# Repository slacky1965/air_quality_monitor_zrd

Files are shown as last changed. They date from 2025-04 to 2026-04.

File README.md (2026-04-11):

# <a id="Top">Air Quality Monitor Zigbee</a>

---

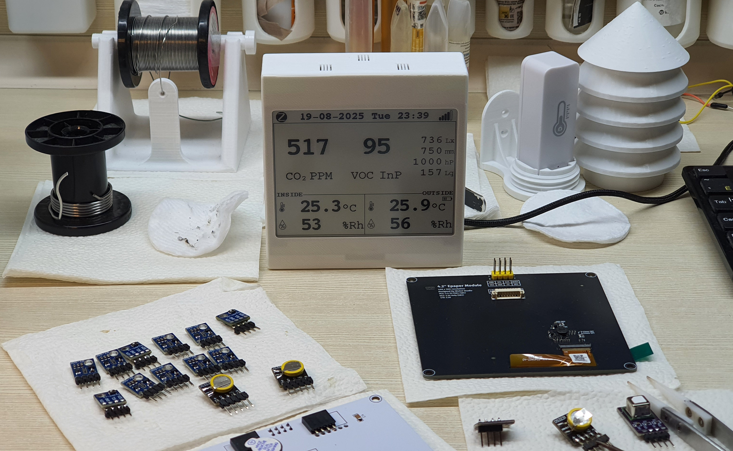
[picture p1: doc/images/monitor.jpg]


---

[Статья на Habr'е](https://habr.com/ru/articles/938388)

[Repository air_quality_monitor_zrd](https://github.com/slacky1965/air_quality_monitor_zrd)

---

* [Описание](#description)
* [Железо](#hardware)
* [Софт](#software)  
* [Принцип работы](#firmware)
* [Настройка](#settings)

## <a id="description">Описание</a>

- Устройство представлят из себя домашний бытовой монитор (далее просто `Монитор`) со встроенными датчиками качества воздуха и климата, показания которых выводятся на экран `epaper` 4.2" и передаются в сеть `Zigbee`.
- `Монитор` выводит следующие показания внутренних датчиков:
	- углекислого газа `CO2`,
	- летучих органичесикх веществ `VOC`,
	- температуры,
	- влажности,
	- атмосферного давления,
	- освещенности.
- `Монитор` имеет возможность отображать показания температуры, влажности и заряда батареи с внешнего датчика напрямую, минуя координатор (прямой биндинг).
- `Монитор` имеет возможность управлять внешним устройством (реле/вентилятор) напрямую, минуя координатор (прямой биндинг) на основании показаний датчиков CO2 и VOC, посылая команды On-Off.
 - `Монитор` может отображать данные в горизонтальном или вертикальном положении, а также менять режим вывода - черное на белом или белое на черном.
- Настраиваемые параметры сохраняет в энергонезависимой памяти модуля `ZTU`.
- Взаимодейстивие с "умными домами" через `zigbee2mqtt`.
- Первоначальная настройка происходит через web-интерфейс `zigbee2mqtt`.
- Подключиться к сети или покинуть сеть `Zigbee` - удерживать кнопку более 5 секунд (светодиод должен погаснуть и начать моргать красным цветом). Время присоединения к сети - полторы минуты (или пока моргает светодиод).
- При одиночном нажатии кнопки `Монитор` высылает отчет по всем показаниям.
- `Монитор` питается от источника постоянного тока напряжением 5 вольт через разъем `USB Type-C` и является роутером.

---

## <a id="hardware">Железо</a>

- В `Мониторе` установлены следующие датчики и модули:
	- `SCD40`      - высокоточный цифровой датчик углекислого газа (`CO2`).
	- `SGP40`      - цифровой датчик летучих органических соединений (`VOC`) от `Sensirion`.
	- `BME280`     - комбинированный цифровой датчик влажности, давления и температуры фирмы `Bosch Sensortec`.
	- `BH1750`     - цифровой датчик освещённости.
	- `DS3231`     - часы реального времени (допускается установка `DS1307`).
	- `WS2812B` 	   - адресные светодиоды, которые помогают визуально по цвету определить качество воздуха.
	- `ZTU`        - модуль `Zigbee` от фирмы `Tuya`, выполенный на чипе `TLSR8258F1KET32` фирмы `Telink`.
	- `WeAct 4.2"` - epaper экран от `WeAct Studio`.

### Схема `Монитора`

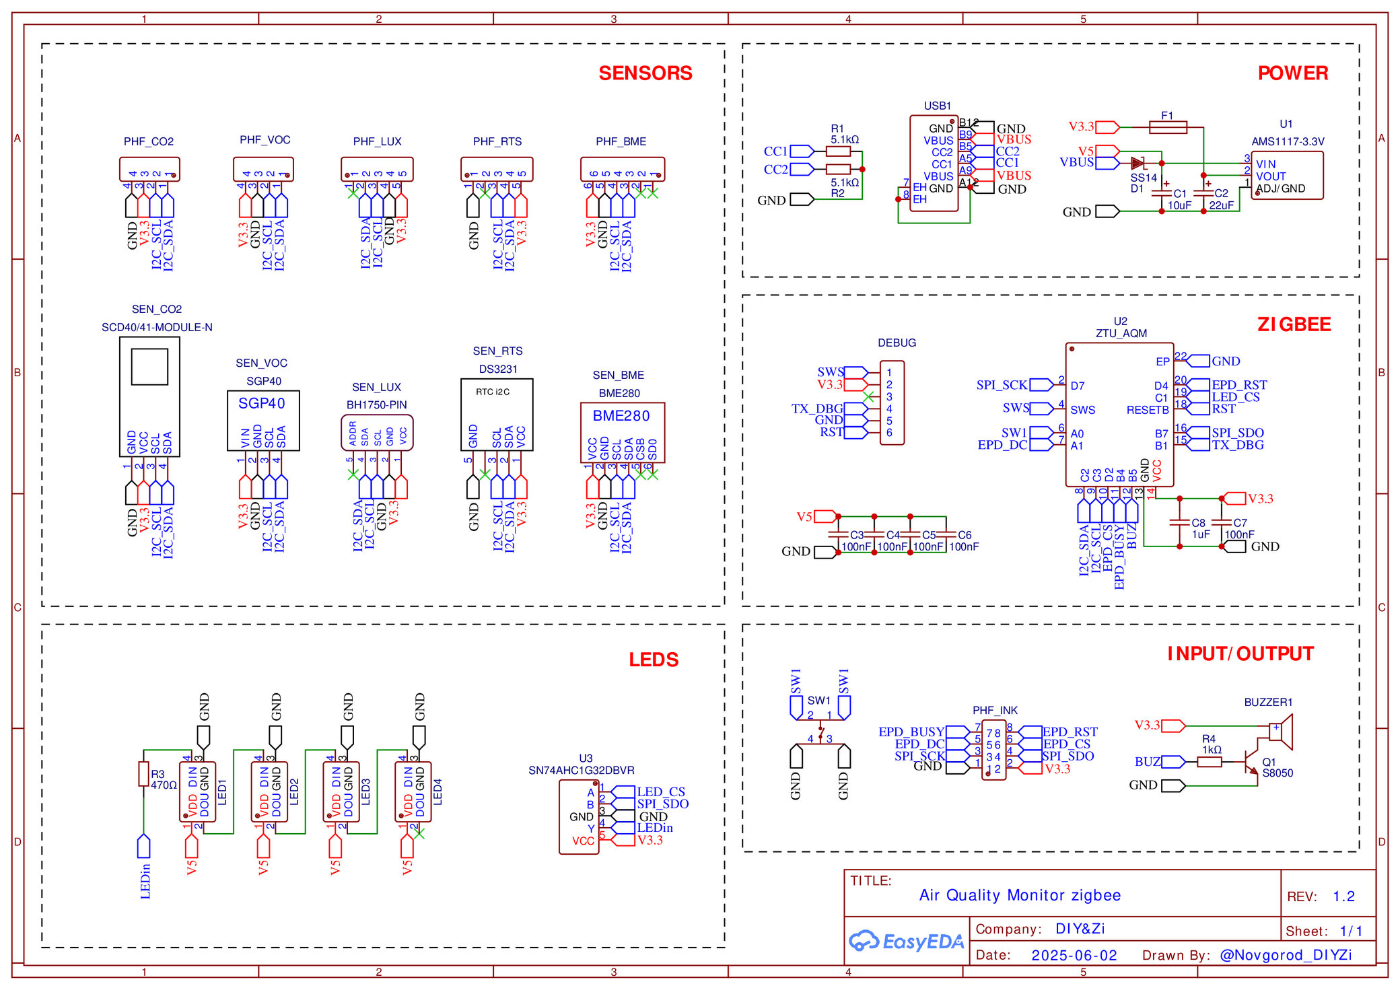
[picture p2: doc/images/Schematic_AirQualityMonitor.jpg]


### Плата `Монитора`

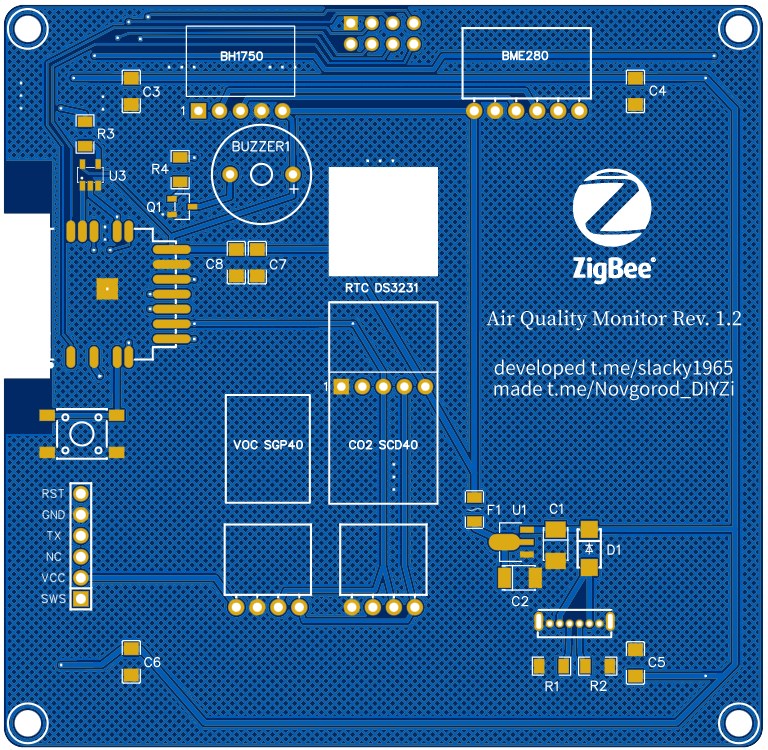
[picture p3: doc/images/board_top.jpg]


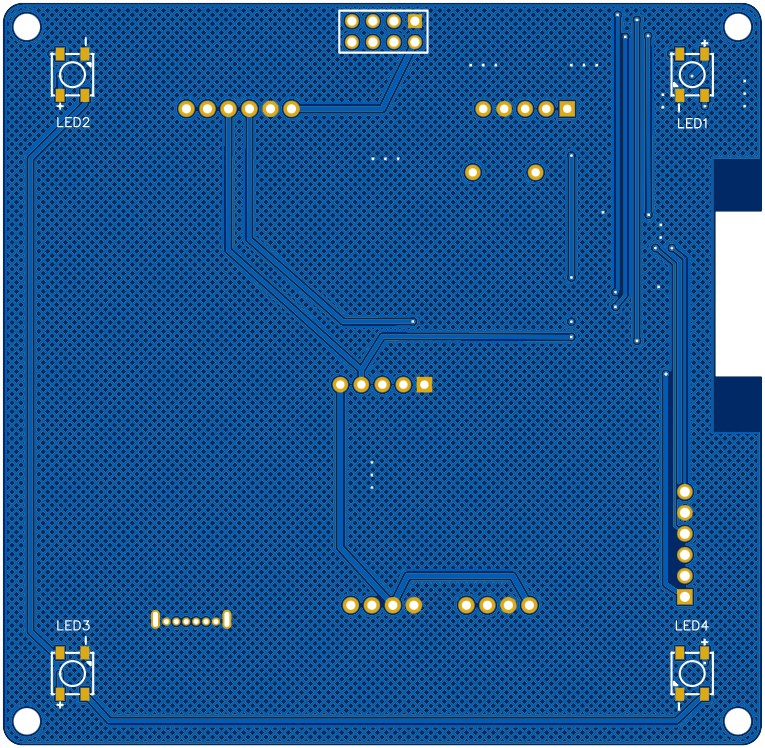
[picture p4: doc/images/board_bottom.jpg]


### Файлы для производства

[Gerber](doc/board/Gerber_AirQualityMonitor-PCB.zip)

[BOM](doc/board/BOM_AirQualityMonitor.csv)

### Корпус для печати

[AQM_case_5.stl](doc/box/AQM_case_5.stl)

[AQM_cover_4.stl](doc/box/AQM_cover_4.stl)

---

## <a id="software">Софт</a>

[Последнюю прошивку](https://github.com/slacky1965/air_quality_monitor_zrd/tree/main/bin)/air_quality_monitor_zrd_Vx.x.xx.bin нужно залить в модуль с помощью [github.com/pvvx/TLSRPGM](https://github.com/pvvx/TLSRPGM) или оригинального программатора от Telink.

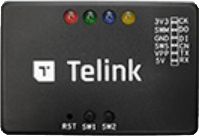
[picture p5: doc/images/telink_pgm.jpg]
Telink PGM


Как сделать недорогой программатор на базе модулей TB-03 или TB-04 можно почитать [тут](https://slacky1965.github.io/electricity_meter_zrd/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)

Проект сформирован таким образом, что его можно собрать обычным make'ом как под Windows, в оболочке [Git Bash](https://git-scm.com/download/win), а также под Linux'ом.

Как добавить проект в Eclipse можно почитать [тут](https://slacky1965.github.io/electricity_meter_zrd/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). Все точно так же, только для другого проекта.

---

## <a id="firmware">Описание работы `Монитора`</a>

При первом старте, если устройство не в сети, выводится заставка, в которой сообщается, что нужно сделать для подключения к сети. Также там можно увидеть название `Монитора`, логотип автора и номер версии прошивки. Время вывода заставки составляет 5 секунд. Если `Монитор` уже в сети, то заставка не выводится.

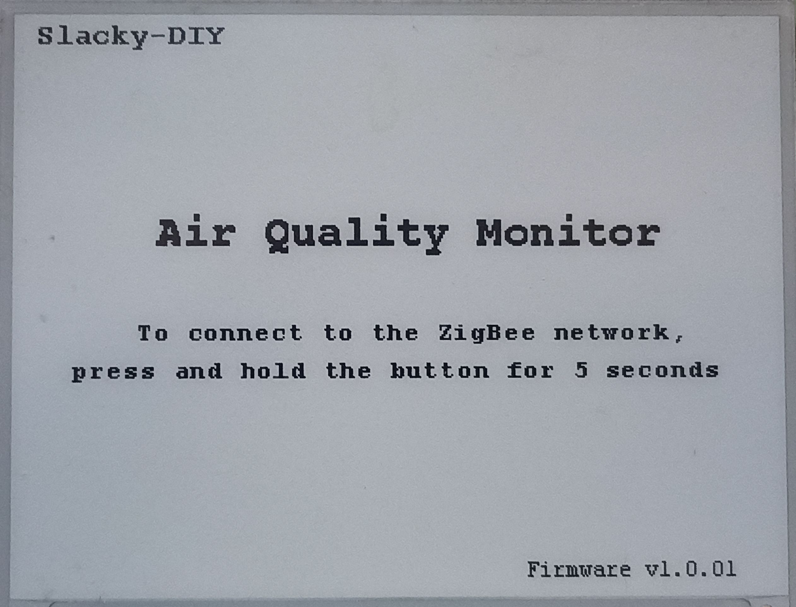
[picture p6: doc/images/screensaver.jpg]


**Описание экрана**

Параметры на экране выводятся независимо от того, в сети устройство или нет. За исключением внешнего датчика. Обновление экрана происходит каждые 10 секунд.

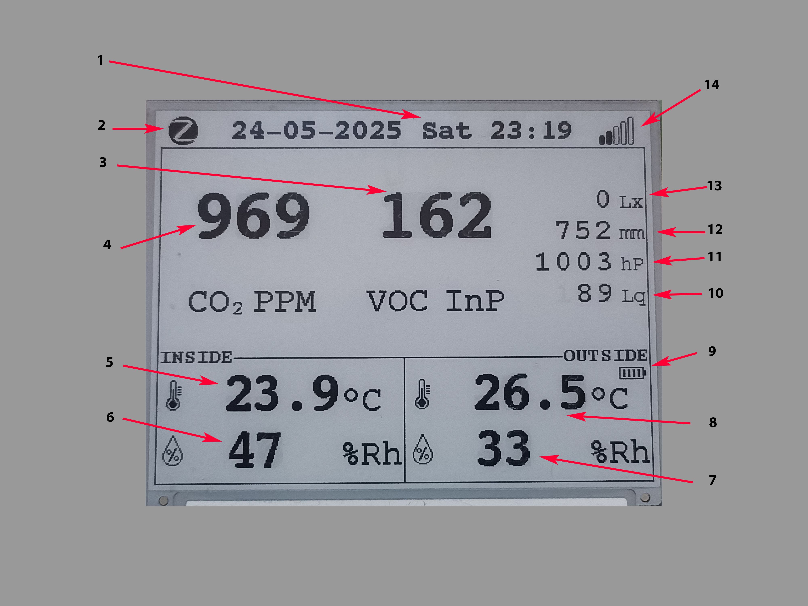
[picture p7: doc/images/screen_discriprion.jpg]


1. Дата, день недели и время.
2. Иконка сети `Zigbee`. Выводится, когда устройство присоеденино к сети, иначе иконка отсутсвует.
3. Значение VOC в index points от 0 до 500.
4. Значение CO2 в PPM от 400 до 2000.
5. Температура внутреннего датчика.
6. Влажность внутреннего датчика.
7. Влажность внешнего датчика.
8. Температура внешнего датчика.
9. Заряд батареи внешнего датчика.
10. LQI - уровень сигнала в единицах от 0 до 255.
11. Давление в гектопаскалях.
12. Давление в мм ртутного столба.
13. Освещение в LUX от 0 до 65535.
14. Уровень сигнала в виде пиктограммы, вычисляется из LQI.

**Сопряжение**

Для сопряжения `Монитора` нужно нажать и удерживать нажатой кнопку более 5 секунд. Отпускать можно, когда светодиод погаснет и начнет мерцать красным светом. Время на сопряжение - полторы минуты (или пока мерцает светодиод). По истечению полутора минут `Монитор` перестает пытаться подключиться к сети.

Если сопряжение прошло успешно, светодиод сообщит об этом, поморгав зеленым цветом три раза. Также на экране в позиции 2 появится иконка сети `Zigbee`.

### Показания

**Дата и часы**

В `Мониторе` используются часы реального времени. Периодически, если `Монитор` сопряжен, он запрашивает время у координатора и синхронизируется с полученным временем.

**CO2**

Показания, снимаемые с датчика `SCD40`, выводятся в `PPM`. Диапазон от 400 до 2000. Для более корректного вычисления содержания углекислого газа в датчик `SCD40` каждый раз, перед измерением, передается значение атмосферного давления с датчика `BME280`. При желании датчик `SCD40` может быть откалиброван принудительно или сброшен на заводские настройки. По умолчанию включена автоматическая калибровка.

**VOC**

Показания передаются в `Index Points`. Датчик `SGP40` выдает некое `RAW` значение. Измерения происходят с периодом в 10 секунд. И это значение передается в специальную библиотеку, которую предоставляет изготовитель этого датчика. В этой библиотеке и вычисляется `Index Points`. Его диапазон от 0 до 500.

**Климатические показания внутреннего датчика**

Климатические показания, снимаемые с датчика `BME280` - это температура, относительная влажность и атмосферное давление. Температурный диапазон измерения от -45 до +85 °С, влажности от 0 до 100% и давления от 300 до 1100 hPa. На экране значение температуры можно выводить в Цельсиях или в Фаренгейтах. Также на экране давление дублируется в мм ртутного столба.

**Освещенность**

Показания с датчика `BH1750` передаются в люксах. Диапазон измерения от 1 до 65535 lx.

**Вспомогательные индикации**

Иконка сети `Zigbee` (на фото позиция 2) - выводится только, если `Монитор` сопряжен с сетью.

Уровень сигнала в `LQI` (на фото позиция 10) - уровень сигнала в цифровом диапазоне от 0 до 255.

Иконка `Уровень сигнала` (на фото позиция 14) - уровень сигнала от 0 до 5 (закрашиваются в черный цвет столбики на иконке). Вычисляется из `LQI`.

**Климатические показания внешнего датчика**

В `Мониторе` предусмотрена возможность выводить температуру, влажность и заряд батареи с внешнего датчика. К сожалению не все датчики умеют передавать свои показания на другое устройство в сети, отличное от координатора. Для получения показаний с внешнего датчика нужно настроить на нем прямой биндинг на `Монитор`. Для этого нужно в web-интерфейсе `zigbee2mqtt` зайти в этот датчик, перейти во вкладку `Bind`, выбрать кластер 1, выбрать `Монитор` и отметить передачу нужных параметров - температуру, влажность и батарейку. И после этого нажать `Bind`. Если по какой-то причине вывод показаний с внешнего датчика станет не нужным, то в этой же вкладке нужно нажать `Unbind`. К сожалению сам `Монитор` не умеет отслеживать, если от него отписались. Поэтому во вкладке `Exposes` самого `Монитора` сделана настройка - `Clear Bind` - если нужно очистить информацию о внешнем датчике. Это нужно сделать, если вы хотите поменять внешний длатчик на другой. Или подождать пару часов - если в течение 2-х часов внешний датчик ничего не присылает, то информация о нем автоматически стирается и данные с экрана очищаются.

Начиная с версии 1.0.06 привязать внешний датчик можно через процедуру "Find and bind". Для ввода `Монитора` в этот режим нужно 5 раз быстро нажать на кнопку, после чего монитор начинает мограть зеленым и светодиодами. После этого на датчике из [проекта](https://github.com/slacky1965/ts0201_tz3000_zed) нужно быстро нажать на кнопку два раза (версия прошивки датчика не ниже 1.0.09).

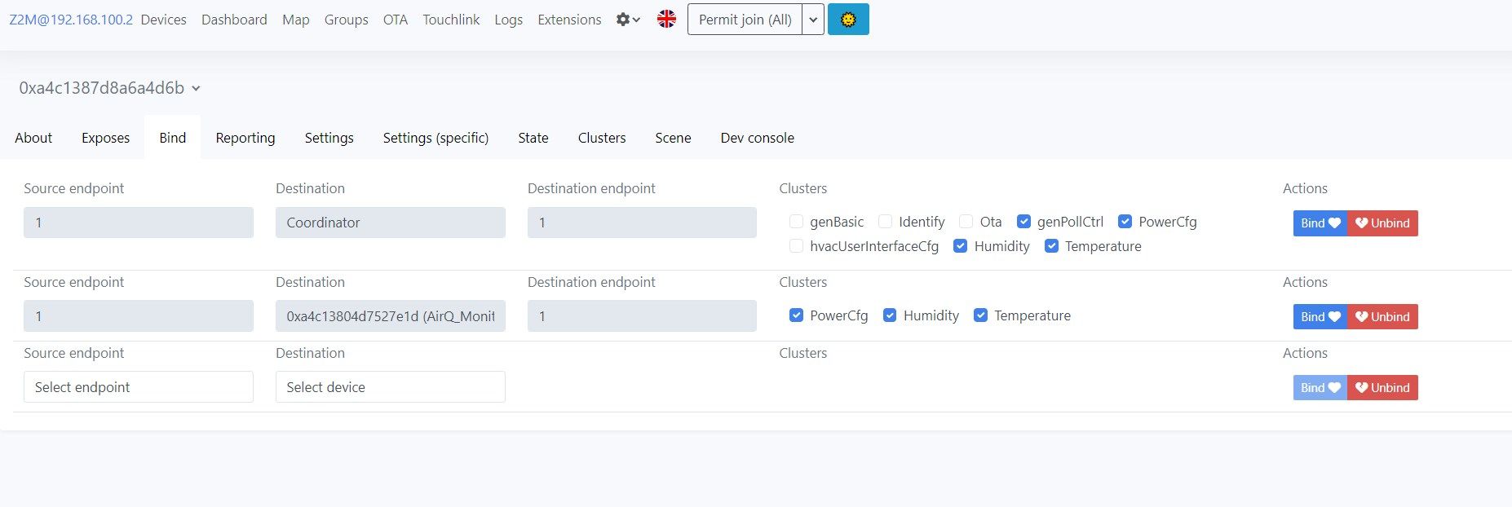
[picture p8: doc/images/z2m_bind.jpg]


**Световая индикация**

Тут все просто. Цвет меняется в зависимости от показаний `CO2` и `VOC`.

- Зеленый - хорошо      (`CO2` 400 ... 600 и `VOC` 0 ... 100)
- Желтый - приемлемо    (`CO2` 601 ... 900 и `VOC` 101 ... 250)
- Пурпурный - плохо     (`CO2` 901 ... 1200 и `VOC` 251 ... 400)
- Красный - очень плохо (`CO2` 1201 ... 2000 и `VOC` 401 ... 500)

Уровень интенсивности свечения можно регулировать от 0 (выключено) до 255 (максимальное свечение).
	
Еще индикатор будет мерцать красным цветом - при попытке сопряжения и зеленым - когда сопряжение произошло. 

---

## <a id="settings">Настройка</a>

**Вкладка `Exposes`**

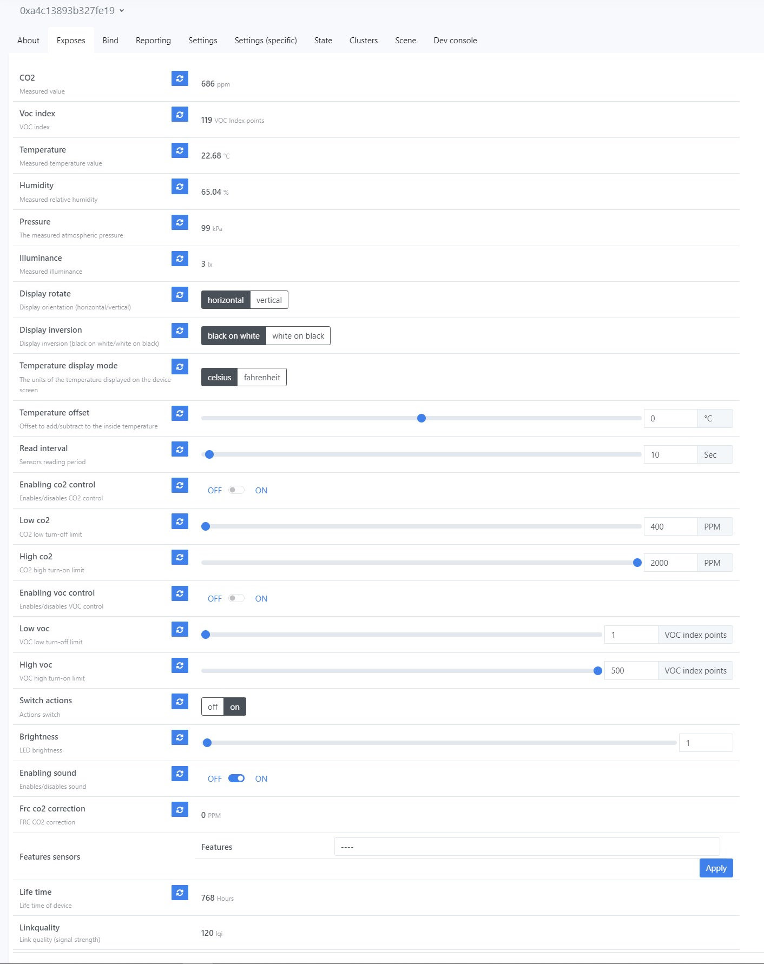
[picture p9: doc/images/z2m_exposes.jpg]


- `CO2` - выводит текущее значение `CO2`.
- `Voc index` - выводит текущее значение `VOC`.
- `Temperature` - выводит текущее значение внутреннего датчика температуры.
- `Humidity` - выводит текущее значение внутреннего датчика влажности.
- `Pressure` - выводит текущее значение внутреннего датчика давления.
- `Illuminance` - выводит текущее значение освещенности.
- `Display rotate` - как выводить информацию, в горизонтальной или вертикальной плоскости.
- `Display inversion` - как выводить информацию, черное на белом или белое на черном.
- `Temperature display mode` - показывать на экране градусы температуры с Цельсиях или в Фаренгейтах.
- `Temperature offset` - подстроить датчик температуры, если по каким-то причинам он показывает неверную температуру. Диапазон настроек от -5 до +5 °С с шагом 0,1. По умолчанию значение подстройки датчика температуры выставлено в 0.
- `Read interval` - как часто будут опрашиваться внутренние датчики. Диапазон опроса от 5 до 600 секунд. По умолчанию 10 секунд.  Это не относится к датчику VOC `SGP40`, его опрос осуществляется по таймеру каждые 10 секунд. Связано с библиотекой вычисления `Index Points` от производителя датчика.
- `Enabling co2 control` - включение и отключение управления внешним устройством по показаниям `CO2`. Также эта настройка активирует звук.
- `Low co2` - нижний порог `CO2`, если значение становится ниже этого порога, внешнее устройство выключается.
- `High co2` - верхний порог `CO2`, если значение становится больше этого порога, внешнее устройство включается. Также, при прохождении порога, Монитор сообщает об этом звуковым сигналом.
- `Enabling voc control` - включение и отключение управления внешним устройством по показаниям `VOC`. Также эта настройка активирует звук.
- `Low voc` - нижний порог `VOC`, если значение становится ниже этого порога, внешнее устройство выключается.
- `High voc` - верхний порог `VOC`, если значение становится больше этого порога, внешнее устройство включается. Также, при прохождении порога, Монитор сообщает об этом звуковым сигналом.
- `Switch actions` - какая команда отправляется для включения и выключения внешнего устройства. Если выставлено в `on`, то для включения внешнего устройства посылается команда `On`, а для выключения `Off`. Если выставлено в `off`, то для включения внешнего устройства посылается команда `Off`, а для выключения `On`.
- `Brightness` - регулировка яркости светодиодной индикации. От 0 до 255. При 0 - светодиоды остаются выключены. 255 - соответсвует максимальной яркости.
- `Enabling sound` - глобальное включение и выключение звука.
- `Frc co2 correction` - выводит значение поправки для `CO2`, если была выполнена принудительная калибровка. Значение может быть как положительным, так и отрицательным.
- `Features sensors` - специфические настройки `Монитора`, которые выведены в отдельную группу.
	- `CO2 forced calibration` - принудительная ручная калибровка датчика `CO2`. Нужно вынести устройство на свежий воздух минут на 15 и потом подать команду калибровки. Датчик примет зачение, измеренное при калибровке за "эталон" и выставит поправку, которую можно увидеть в `Frc co2 correction`.
	- `CO2 factory reset` - сброс датчика `CO2` к заводским настройкам. Значение ручной калибровки, если таковая была сделана, тоже сбрасываются.
	- `Bind reset` - очистит таблицу биндинга внешнего датчика температуры/влажности.

---

**Вкладка `Bind`**

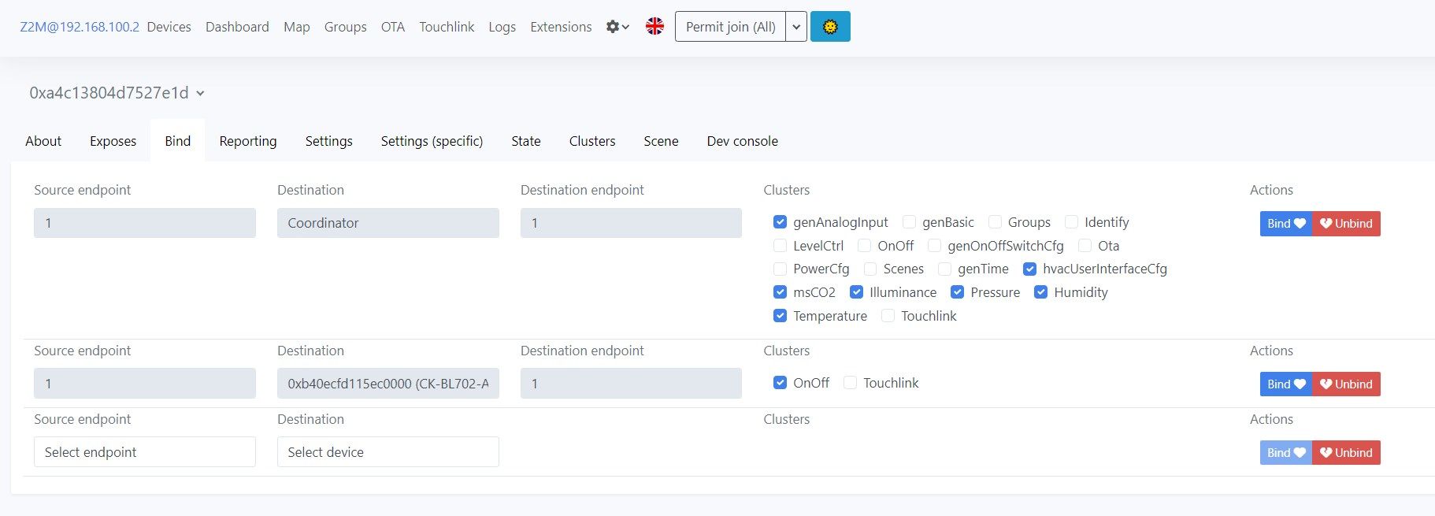
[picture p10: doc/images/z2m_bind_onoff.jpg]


Настройка прямого биндинга на исполнительное устройство - реле/вентилятор и т.п., которое будет включаться и выключаться, если включен `Enabling co2 control` и/или `Enabling voc control` и выставлены соответствующие пороги. Нужно только учесть, что если минимальный порог выставлен слишком низким, то внешнее устройство никогда не выключится. Для настройки, нужно выбрать эндпоинт в `Source endpoint`, где на `Мониторе` находится кластер `On-Off` - это 1, далее выбрать внешнее устройство в `Destination` и кластер на внешнем устройстве в `Destination endpoint`, отметить галочкой `OnOff` и нажать на `Bind` справа. Если управление станет не нужным или нужно будет изменить внешнее устройство, нужно нажать `Unbind`.

---

**Вкладка `Reporting`**

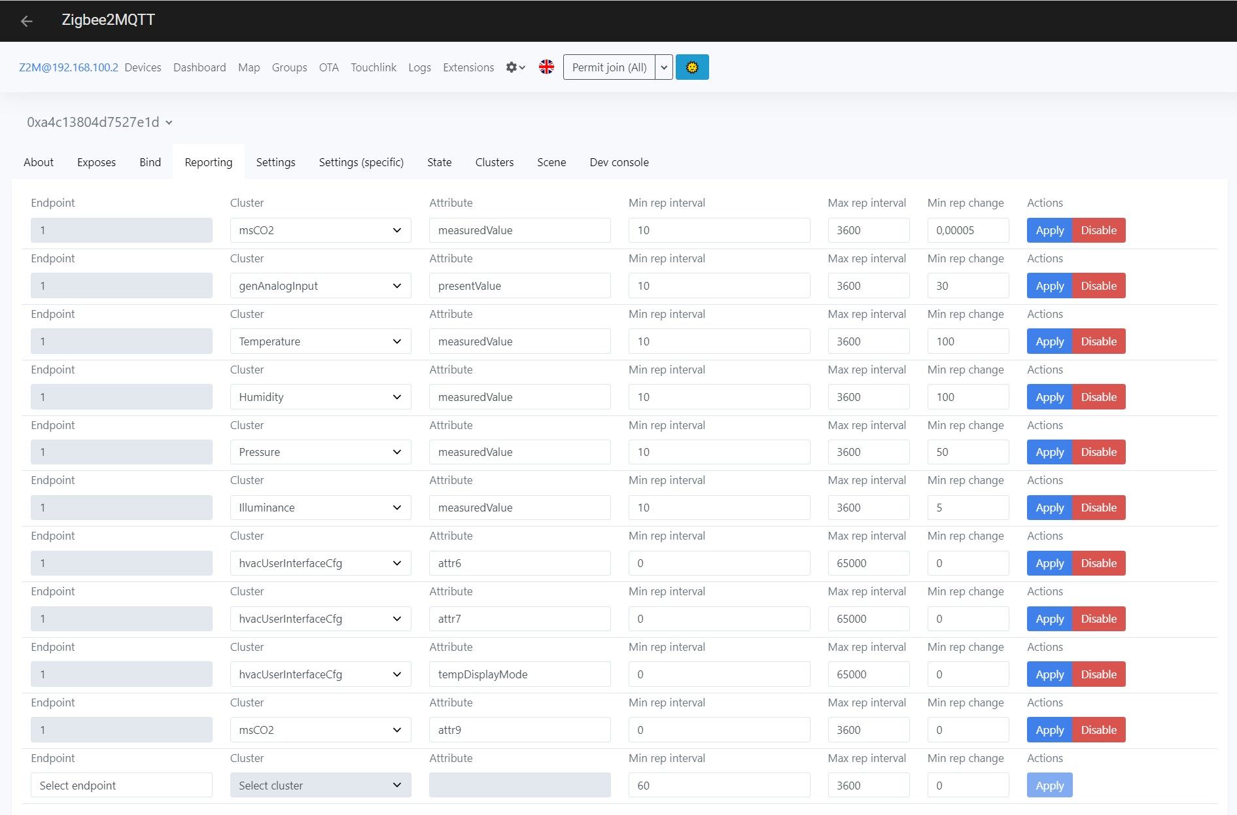
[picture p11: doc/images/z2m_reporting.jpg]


Настройка репортинга.

Репортинг кастомных атрибутов лучше не трогать. Их можно сразу отличить по имени - `attr6`, `attr7` и т.д. 

Репортинг основных параметров - `CO2`, `VOC`, `Temperature`, `Humidity`, `Pressure` и `Illuminance` можно настроить в соответствии с вашими желаниями. 

---

**Настройки с помощью кнопки на `Мониторе`**

- Нажать один раз - происходит отправка отчетов по всем параметрам в сеть `Zigbee`.
- Нажать быстро два раза - экран меняет ориентацию на 90 градусов.
- Нажать быстро три раза - экран меняет вывод с `черного на белом` на `белое на черном` и наоборот.
- Нажать быстро четыре раза - изменит вывод температуры с Цельсия на Фаренгейты и наоборот.
- Нажать быстро пять раз - запустить процедуру "Find and bind".
- Нажать быстро шесть раз - перезагрузить Монитор.

Каждое нажатие кнопки сопровождается промаргиванием световой индикации красным цветом.

---

Связаться со мной можно в **[Telegram](https://t.me/slacky1965)**.

### Если захотите отблагодарить автора, то это можно сделать через [ЮMoney](https://yoomoney.ru/to/4100118300223495)

---

## История версий
- 1.0.01
	- Начало.
- 1.0.02
	- Добавлен параметр `LifeTime` - время наработки `Монитора` в часах.
	- Добавлена возможность перезагрузки `Монитора` по кнопке.
- 1.0.03
	- Измененая последовательность запуска тасков опроса датчиков. Уменьшена очередь.
	- Устранена проблема с репортингом.
- 1.0.04
	- Добавлена сигнализация звуком по нарастающей при его включении и по ниспадающей при его выключении.
	- Немного измена процедура `factory reset`.
- 1.0.05
	- Добавлена [полная перезагрузка (очистка) экрана](https://github.com/slacky1965/air_quality_monitor_zrd/issues/15) два раза в сутки. В 03:00 и в 15:00.
	- Откорректировано получение значения `LQI`, когда `Монитор` работает не напрямую через координатор, а через роутер.
	- Исправлен [вывод температуры](https://github.com/slacky1965/air_quality_monitor_zrd/issues/16) на экран (было 1 - 10.7°С = 10.7°С, 2 - 9.6°С = 9.67°С).
	- Добавлен значок `динамик включен` и `динамик выключен` (визуально отображает включен или выключен звук).
	- Добавлен принудительный `rejoin` после обновления `ОТА`.
- 1.0.06
	- Исправлен [вывод влажности](https://github.com/slacky1965/air_quality_monitor_zrd/issues/16#issuecomment-3903385260) на экран (было 1 - 100% = 100%, 2 - 83% = 830%).
	- Добалена возможность привязать внешний датчик температуры из [проекта](https://github.com/slacky1965/ts0201_tz3000_zed) через процедуру "Find and bind" (версия прошивки датчика не ниже 1.0.09).
	- Удален принудительный `rejoin` после обновления.
	- Добавлен `анонс` устройства при старте.
	- Изменена процедура опроса кнопки.
	
[Наверх](#Top)

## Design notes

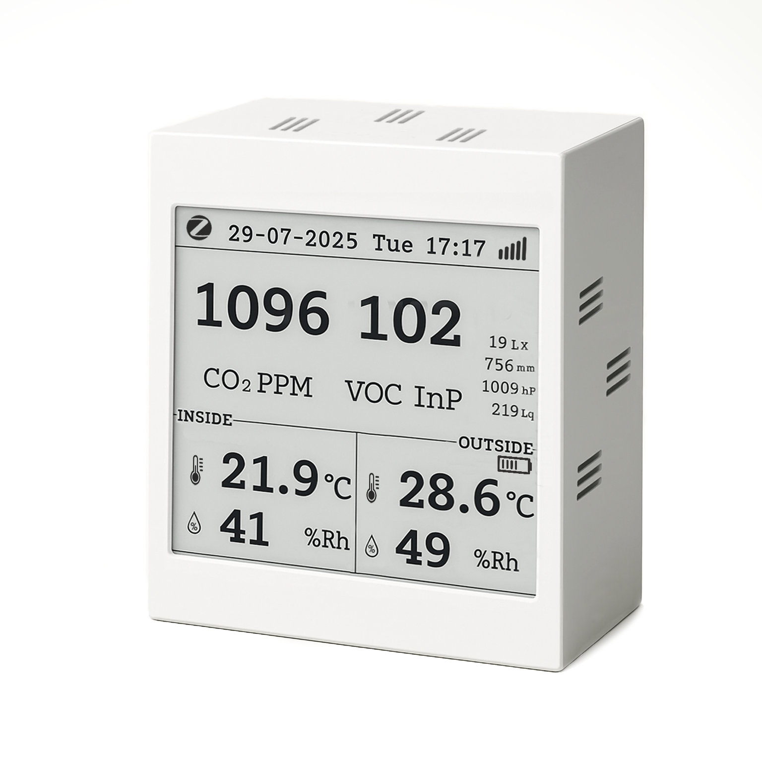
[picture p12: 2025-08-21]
doc/images/Monitor_New.jpg

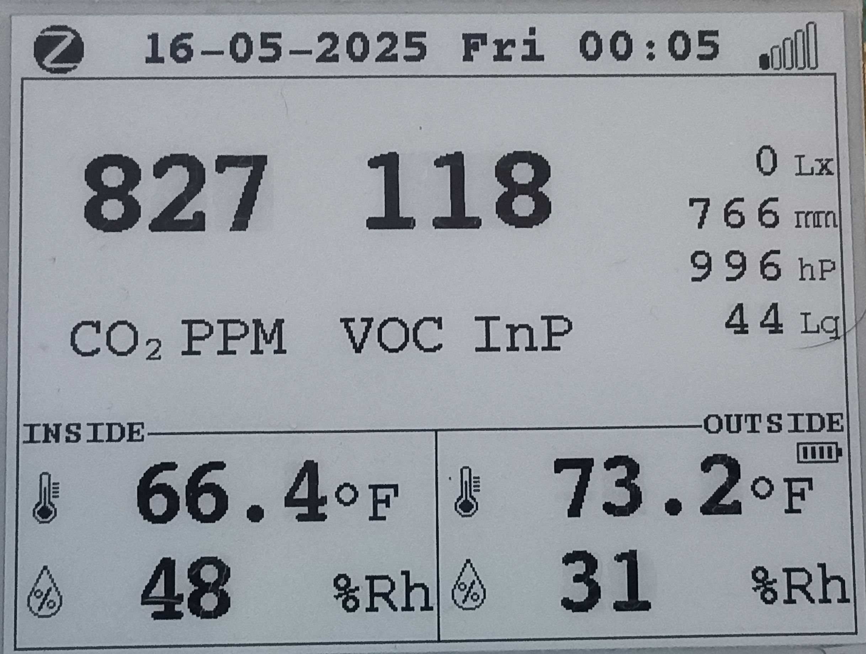
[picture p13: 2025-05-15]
doc/images/screenF.jpg

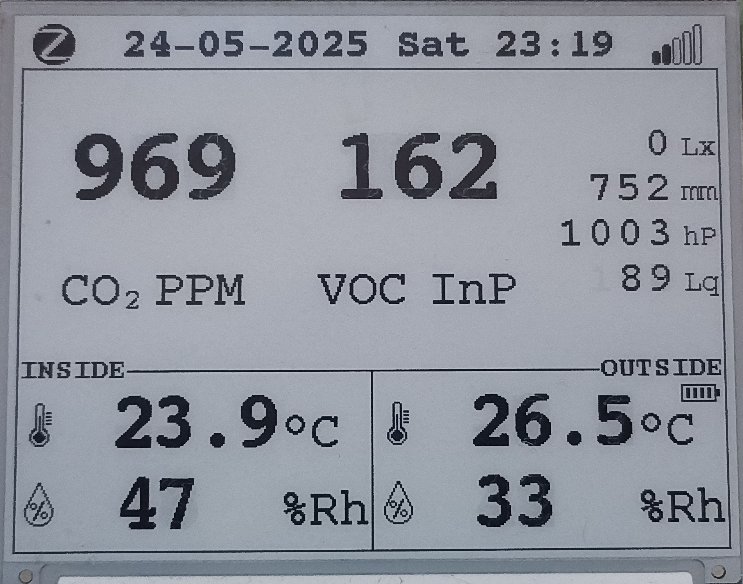
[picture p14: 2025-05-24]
doc/images/screen.jpg

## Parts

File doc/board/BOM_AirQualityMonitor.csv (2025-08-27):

ID | Name | Designator | Footprint | Quantity | Manufacturer Part | Manufacturer | Supplier | Supplier Part
1 | PM254V-12-08-H85_C2834799 | PHF_INK | HDR-TH_8P-P2.54-V-F-R2-C4-S2.54 | 1 | PM254V-12-08-H85 | XFCN(兴飞) | LCSC | C2834799
2 | XL-5050RGBC-WS2812B | LED1,LED2,LED3,LED4 | LED-SMD_4P-L5.0-W5.0-BL_XL-5050RGBC | 4 | XL-5050RGBC-WS2812B | XINGLIGHT(成兴光) | LCSC | C2843785
3 | S8050 | Q1 | SOT-23-3_L2.9-W1.6-P1.90-LS2.8-BR | 1 | S8050 | Hottech(合科泰) | LCSC | C181158
4 | PM254-1-06-W-8.5 | PHF_BME | HDR-TH_6P-P2.54-H-F-W10.0-N | 1 | PM254-1-06-W-8.5 | HCTL(华灿天禄) | LCSC | C2897388
5 | PM254-1-04-W-8.5 | PHF_CO2,PHF_VOC | HDR-TH_4P-P2.54-H-F-W10.0-N | 2 | PM254-1-04-W-8.5 | HCTL(华灿天禄) | LCSC | C2897386
6 | DW254W-11-05-85 | PHF_LUX,PHF_RTS | CONN-TH_5P-P2.54_DEALON_DW254W-11-05-85 | 2 | DW254W-11-05-85 | DEALON(德艺隆) | LCSC | C2935995
7 | ZTU_AQM | U2 | WIRELM-SMD_ZTU_AQM | 1 | ZTU(ujzh) | TUYA(涂鸦） | LCSC | C2844250
8 | SN74AHC1G32DBVR | U3 | SOT-23-5_L3.0-W1.7-P0.95-LS2.8-BR | 1 | SN74AHC1G32DBVR | TI(德州仪器) | LCSC | C7470
9 | 2.3kHz | BUZZER1 | BUZ-TH_BD12.0-P7.60-D0.6-FD | 1 | TMB12A05 | 华能 | LCSC | C96093
10 | 470Ω | R3 | R1206 | 1 | 1206W4F4700T5E | UNI-ROYAL(厚声) | LCSC | C4502
11 | 1kΩ | R4 | R1206 | 1 | 1206W4F1001T5E | UNI-ROYAL(厚声) | LCSC | C4410
12 | TYPE-C 6P LCH10.0 | USB1 | USB-TH_TYPE-C-6P-LCH10.0 | 1 | TYPE-C 6P LCH10.0 | SHOU HAN(首韩) | LCSC | C5187470
13 | 10uF | C1 | CAP-SMD_L3.5-W2.8-R-RD | 1 | TAJB106K025RNJ | Kyocera AVX | LCSC | C7194
14 | 22uF | C2 | CASE-B_3528 | 1 | TAJB226K016RNJ | Kyocera AVX | LCSC | C8020
15 | 100nF | C3,C4,C5,C6,C7 | C1206 | 5 | CL31B104KBCNNNC | SAMSUNG(三星) | LCSC | C24497
16 | 1uF | C8 | C1206 | 1 | CL31B105KBHNNNE | SAMSUNG(三星) | LCSC | C1848
17 | SS14 | D1 | DO-214AC_L4.3-W2.7-LS5.3-RD | 1 | SMAJ170A-E3/61 | VISHAY(威世) | LCSC | C467966
18 | JK-NSMD050-30V | F1 | F1206 | 1 | JK-nSMD050-30 | JK(金科) | LCSC | C720075
19 | 5.1kΩ | R1,R2 | R1206 | 2 | 1206W4F5101T5E | UNI-ROYAL(厚声) | LCSC | C26033
20 | AMS1117-3.3V | U1 | SOT-89-3_L4.5-W2.5-P1.50-LS4.2-BR | 1 | AMS1117-3.3V | MSKSEMI(美森科) | LCSC | C5120796
21 | TS-1102SD-A-Q-R | SW1 | SW-SMD_4P-L6.0-W6.0-P4.50-LS9.2 | 1 | TS-1102SD-A-Q-R | XKB Connectivity(中国星坤) | LCSC | C3010217

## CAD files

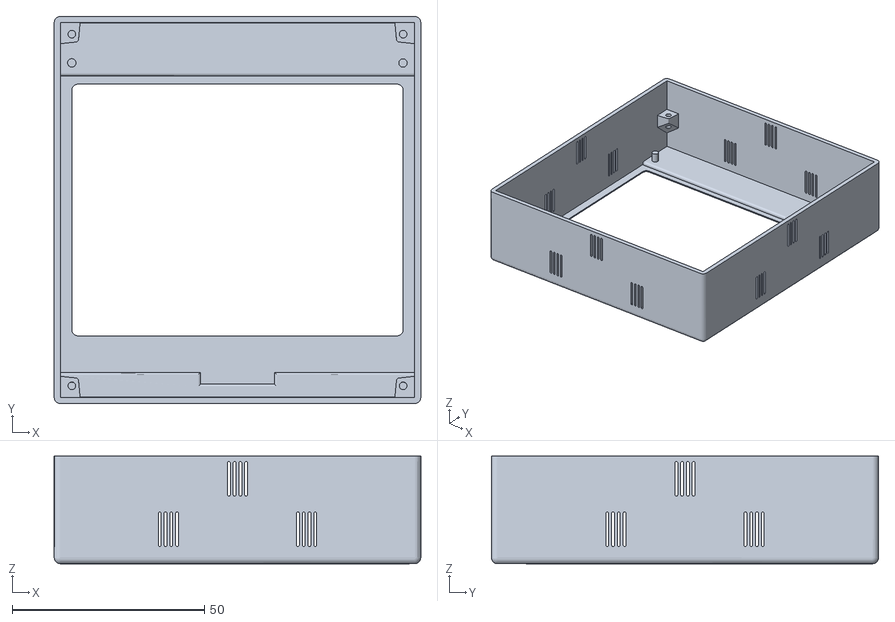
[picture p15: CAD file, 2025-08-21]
doc/box/AQM_case_5.stl
95.4 x 100.7 x 28.0

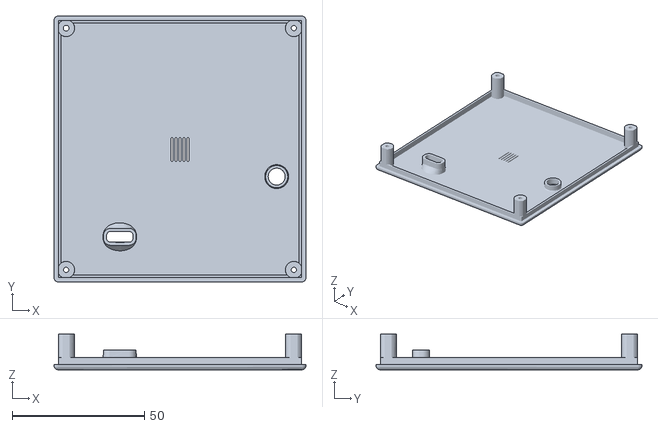
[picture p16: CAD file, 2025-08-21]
doc/box/AQM_cover_4.stl
95.4 x 100.7 x 13.5

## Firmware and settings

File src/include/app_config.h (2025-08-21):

#ifndef SRC_INCLUDE_APP_CONFIG_H_
#define SRC_INCLUDE_APP_CONFIG_H_

#define READ_SENSORS_PERIOD_MIN         5
#define READ_SENSORS_PERIOD_MAX         600
#define TEMPERATURE_OFFSET_MIN         -500
#define TEMPERATURE_OFFSET_MAX          500
#define VOC_ONOFF_MIN                   1
#define VOC_ONOFF_MAX                   500
#define VOC_ONOFF_ENABLED               0x01
#define VOC_ONOFF_DISABLED              0x00
#define CO2_ONOFF_MIN                   400
#define CO2_ONOFF_MAX                   2000
#define CO2_ONOFF_ENABLED               0x01
#define CO2_ONOFF_DISABLED              0x00

#define DEFAULT_ROTATE                  APP_EPD_ROTATE_0
#define DEFAULT_INVERSION               APP_EPD_INVERSION_OFF
#define DEFAULT_READ_SENSORS_PERIOD     (READ_SENSORS_PERIOD_MIN * 2)
#define DEFAULT_BRIGHTNESS              25
#define DEFAULT_DISPLAY_MODE            ZCL_DISPLAY_MODE_CELSIUS
#define DEFAULT_SOUND                   1
#define DEFAULT_TEMPERATURE_OFFSET      0
#define DEFAULT_CO2_ONOFF               CO2_ONOFF_DISABLED
#define DEFAULT_CO2_ONOFF_MIN           CO2_ONOFF_MIN
#define DEFAULT_CO2_ONOFF_MAX           CO2_ONOFF_MAX
#define DEFAULT_VOC_ONOFF               VOC_ONOFF_DISABLED
#define DEFAULT_VOC_ONOFF_MIN           VOC_ONOFF_MIN
#define DEFAULT_VOC_ONOFF_MAX           VOC_ONOFF_MAX


typedef struct __attribute__((packed)) {
    uint8_t     rotate;
    uint8_t     inversion;
    uint16_t    read_sensors_period;
    uint8_t     brightness;             /* level                         */
    uint8_t     d_mode;                 /* Display mode C or F           */
    int16_t     temperature_offset;     /* -5 ... +5 with step 0.1 * 100 */
    uint8_t     voc_onoff;              /* 0 - disabled, 1 - enabled     */
    uint16_t    voc_onoff_low;          /* 50                            */
    uint16_t    voc_onoff_high;         /* 500                           */
    uint8_t     co2_onoff;              /* 0 - disabled, 1 - enabled     */
    uint16_t    co2_onoff_low;          /* 400                           */
    uint16_t    co2_onoff_high;         /* 2000                          */
    int16_t     co2_frc;                /* offset co2                    */
    uint8_t     sound;                  /* 0 - disabled, 1 - enabled     */
    uint8_t     crc;
} config_t;

extern config_t config;

uint8_t checksum(uint8_t *data, uint16_t length);
nv_sts_t config_save();
nv_sts_t config_restore();

#endif /* SRC_INCLUDE_APP_CONFIG_H_ */

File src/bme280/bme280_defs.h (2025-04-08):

/**
* Copyright (c) 2020 Bosch Sensortec GmbH. All rights reserved.
*
* BSD-3-Clause
*
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
* 1. Redistributions of source code must retain the above copyright
*    notice, this list of conditions and the following disclaimer.
*
* 2. Redistributions in binary form must reproduce the above copyright
*    notice, this list of conditions and the following disclaimer in the
*    documentation and/or other materials provided with the distribution.
*
* 3. Neither the name of the copyright holder nor the names of its
*    contributors may be used to endorse or promote products derived from
*    this software without specific prior written permission.
*
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
* @file       bme280_defs.h
* @date       2020-12-17
* @version    v3.5.1
*
*/

#ifndef _BME280_DEFS_H
#define _BME280_DEFS_H

/********************************************************/
/* header includes */
//#ifdef __KERNEL__
//#include <linux/types.h>
//#include <linux/kernel.h>
//#else
//#include <stdint.h>
//#include <stddef.h>
//#endif
#include "app_main.h"

/********************************************************/
/*! @name       Common macros               */
/********************************************************/

#if !defined(UINT8_C) && !defined(INT8_C)
#define INT8_C(x)    S8_C(x)
#define UINT8_C(x)   U8_C(x)
#endif

#if !defined(UINT16_C) && !defined(INT16_C)
#define INT16_C(x)   S16_C(x)
#define UINT16_C(x)  U16_C(x)
#endif

#if !defined(INT32_C) && !defined(UINT32_C)
#define INT32_C(x)   S32_C(x)
#define UINT32_C(x)  U32_C(x)
#endif

#if !defined(INT64_C) && !defined(UINT64_C)
#define INT64_C(x)   S64_C(x)
#define UINT64_C(x)  U64_C(x)
#endif

/**@}*/
/**\name C standard macros */
#ifndef NULL
#ifdef __cplusplus
#define NULL         0
#else
#define NULL         ((void *) 0)
#endif
#endif

/******************************************************************************/
/*! @name        Compiler switch macros Definitions                */
/******************************************************************************/
#ifndef BME280_64BIT_ENABLE /*< Check if 64-bit integer (using BME280_64BIT_ENABLE) is enabled */
#ifndef BME280_32BIT_ENABLE /*< Check if 32-bit integer (using BME280_32BIT_ENABLE) is enabled */
#ifndef BME280_DOUBLE_ENABLE /*< If any of the integer data types not enabled then enable BME280_DOUBLE_ENABLE */
#define BME280_DOUBLE_ENABLE
#endif
#endif
#endif

/******************************************************************************/
/*! @name        General Macro Definitions                */
/******************************************************************************/
#ifndef TRUE
#define TRUE                                      UINT8_C(1)
#endif
#ifndef FALSE
#define FALSE                                     UINT8_C(0)
#endif

/*!
 * BME280_INTF_RET_TYPE is the read/write interface return type which can be overwritten by the build system.
 */
#ifndef BME280_INTF_RET_TYPE
#define BME280_INTF_RET_TYPE                      int8_t
#endif

/*!
 * The last error code from read/write interface is stored in the device structure as intf_rslt.
 */
#ifndef BME280_INTF_RET_SUCCESS
#define BME280_INTF_RET_SUCCESS                   INT8_C(0)
#endif

/*! @name API success code */
#define BME280_OK                                 INT8_C(0)

/*! @name API error codes */
#define BME280_E_NULL_PTR                         INT8_C(-1)
#define BME280_E_COMM_FAIL                        INT8_C(-2)
#define BME280_E_INVALID_LEN                      INT8_C(-3)
#define BME280_E_DEV_NOT_FOUND                    INT8_C(-4)
#define BME280_E_SLEEP_MODE_FAIL                  INT8_C(-5)
#define BME280_E_NVM_COPY_FAILED                  INT8_C(-6)

/*! @name API warning codes */
#define BME280_W_INVALID_OSR_MACRO                INT8_C(1)

/*! @name BME280 chip identifier */
#define BME280_CHIP_ID                            UINT8_C(0x60)

/*! @name I2C addresses */
#define BME280_I2C_ADDR_PRIM                      UINT8_C(0x76)
#define BME280_I2C_ADDR_SEC                       UINT8_C(0x77)

/*! @name Register Address */
#define BME280_REG_CHIP_ID                        UINT8_C(0xD0)
#define BME280_REG_RESET                          UINT8_C(0xE0)
#define BME280_REG_TEMP_PRESS_CALIB_DATA          UINT8_C(0x88)
#define BME280_REG_HUMIDITY_CALIB_DATA            UINT8_C(0xE1)
#define BME280_REG_CTRL_HUM                       UINT8_C(0xF2)
#define BME280_REG_STATUS                         UINT8_C(0xF3)
#define BME280_REG_PWR_CTRL                       UINT8_C(0xF4)
#define BME280_REG_CTRL_MEAS                      UINT8_C(0xF4)
#define BME280_REG_CONFIG                         UINT8_C(0xF5)
#define BME280_REG_DATA                           UINT8_C(0xF7)

/*! @name Macros related to size */
#define BME280_LEN_TEMP_PRESS_CALIB_DATA          UINT8_C(26)
#define BME280_LEN_HUMIDITY_CALIB_DATA            UINT8_C(7)
#define BME280_LEN_P_T_H_DATA                     UINT8_C(8)
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

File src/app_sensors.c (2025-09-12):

#include "app_main.h"

#define BIND_TIMEOUT  TIMEOUT_2HOUR //TIMEOUT_10MIN //

static int16_t  outside_temperature = 0x8000;
static uint16_t outside_humidity = 0xffff;
static uint8_t  outside_battery_percent = 0xff;

//static uint8_t t_index = 0;
//static uint16_t b_addr;

static bool sw_onoff = false;

static bind_outside_sensor_t bind_outside_sensor = {
        .used = 0,
        .checkBindTimerEvt = NULL,
};

static void cmdOnOff(uint8_t command) {
    epInfo_t dstEpInfo;
    TL_SETSTRUCTCONTENT(dstEpInfo, 0);

    dstEpInfo.profileId = HA_PROFILE_ID;

    dstEpInfo.dstAddrMode = APS_DSTADDR_EP_NOTPRESETNT;

    /* command 0x00 - off, 0x01 - on, 0x02 - toggle */

    switch(command) {
        case ZCL_CMD_ONOFF_OFF:
#if UART_PRINTF_MODE && DEBUG_ONOFF
            printf("OnOff command: off\r\n");
#endif /* UART_PRINTF_MODE */
            zcl_onOff_offCmd(APP_ENDPOINT1, &dstEpInfo, FALSE);
            break;
        case ZCL_CMD_ONOFF_ON:
#if UART_PRINTF_MODE && DEBUG_ONOFF
            printf("OnOff command: on\r\n");
#endif /* UART_PRINTF_MODE */
            zcl_onOff_onCmd(APP_ENDPOINT1, &dstEpInfo, FALSE);
            break;
        case ZCL_CMD_ONOFF_TOGGLE:
#if UART_PRINTF_MODE && DEBUG_ONOFF
            printf("OnOff command: toggle\r\n");
#endif /* UART_PRINTF_MODE */
            zcl_onOff_toggleCmd(APP_ENDPOINT1, &dstEpInfo, FALSE);
            break;
        default:
            break;
    }
}

static void proc_co2_voc_onoff(void *args) {

    bool co2_ctrl_off = false;
    bool co2_ctrl_on = false;
    bool voc_ctrl_off = false;
    bool voc_ctrl_on = false;

    zcl_onOffSwitchCfgAttr_t *onoffCfgAttrs = zcl_onOffSwitchCfgAttrGet();

    if(zb_isDeviceJoinedNwk()) {

        uint16_t voc = app_sgp40_get_voc();
        uint16_t co2 = app_scd4x_get_co2();

//        printf("co2: %d, voc: %d\r\n", co2, voc);

//        if (co2 < CO2_ONOFF_MIN || voc < VOC_ONOFF_MIN)
//            return;

        if (config.co2_onoff) {
            if (co2 >= config.co2_onoff_high)
                co2_ctrl_on = true;
            if (co2 <= config.co2_onoff_low)
                co2_ctrl_off = true;
            if (co2_ctrl_off && co2_ctrl_on)
                co2_ctrl_on = false;
        }

        if (config.voc_onoff) {
            if (voc >= config.voc_onoff_high)
                voc_ctrl_on = true;
            if (voc <= config.voc_onoff_low)
                voc_ctrl_off = true;
            if (voc_ctrl_off && voc_ctrl_on)
                voc_ctrl_on = false;
        }

        if (sw_onoff && !config.co2_onoff && !config.voc_onoff) {
            sw_onoff = false;
            switch(onoffCfgAttrs->switchActions) {
                case ZCL_SWITCH_ACTION_ON_OFF:
                    cmdOnOff(ZCL_CMD_ONOFF_ON);
                    break;
                case ZCL_SWITCH_ACTION_OFF_ON:
                    cmdOnOff(ZCL_CMD_ONOFF_OFF);
                    break;
//                    case ZCL_SWITCH_ACTION_TOGGLE:
//                        cmdOnOff(ZCL_CMD_ONOFF_TOGGLE);
//                        break;
                default:
                    break;
            }
        }


        if ((co2_ctrl_on && config.co2_onoff) || (voc_ctrl_on && config.voc_onoff)) {
            if (!sw_onoff) {
                sw_onoff = true;
                if (config.sound)
                    sound_start(3, 20, 100, SOUND_SAME);
#if UART_PRINTF_MODE && DEBUG_ONOFF
                printf("Switch action: 0x0%x\r\n", onoffCfgAttrs->switchActions);
#endif /* UART_PRINTF_MODE */
                switch(onoffCfgAttrs->switchActions) {
                    case ZCL_SWITCH_ACTION_ON_OFF:
                        cmdOnOff(ZCL_CMD_ONOFF_OFF);
                        break;
                    case ZCL_SWITCH_ACTION_OFF_ON:
                        cmdOnOff(ZCL_CMD_ONOFF_ON);
                        break;
//                    case ZCL_SWITCH_ACTION_TOGGLE:
//                        cmdOnOff(ZCL_CMD_ONOFF_TOGGLE);
//                        break;
                    default:
                        break;
                }
            }
        }

        if ((co2_ctrl_off && config.co2_onoff && !voc_ctrl_on) || (voc_ctrl_off && config.voc_onoff && !co2_ctrl_on)) {
            if (sw_onoff) {
                sw_onoff = false;
#if UART_PRINTF_MODE && DEBUG_ONOFF
                printf("Switch action: 0x0%x\r\n", onoffCfgAttrs->switchActions);
#endif /* UART_PRINTF_MODE */
                switch(onoffCfgAttrs->switchActions) {
                    case ZCL_SWITCH_ACTION_ON_OFF:
                        cmdOnOff(ZCL_CMD_ONOFF_ON);
                        break;
                    case ZCL_SWITCH_ACTION_OFF_ON:
                        cmdOnOff(ZCL_CMD_ONOFF_OFF);
                        break;
//                    case ZCL_SWITCH_ACTION_TOGGLE:
//                        cmdOnOff(ZCL_CMD_ONOFF_TOGGLE);
//                        break;
                    default:
                        break;
                }
            }
        }
    }

//    printf("sw_onoff: %d, co2_ctrl_off: %d, co2_ctrl_on: %d, voc_ctrl_off: %d, voc_ctrl_on: %d\r\n", sw_onoff, co2_ctrl_off, co2_ctrl_on, voc_ctrl_off, voc_ctrl_on);
}

static void mesurement_sgp40(void *args) {
    app_sgp40_measurement();
    TL_SCHEDULE_TASK(proc_co2_voc_onoff, NULL);
}

static void mesurement_scd4x(void *args) {
    app_scd4x_measurement();
    TL_SCHEDULE_TASK(mesurement_sgp40, NULL);
}

static void mesurement_bh1750(void *args) {
    app_bh1750_measurement();
    TL_SCHEDULE_TASK(mesurement_scd4x, NULL);
}

static void mesurement_bme280(void *args) {
    app_bme280_measurement();
    TL_SCHEDULE_TASK(mesurement_bh1750, NULL);
}

int32_t app_mesurementCb(void *args) {

//    print_time();
//    printf("app_mesurementCb\r\n");

    TL_SCHEDULE_TASK(mesurement_bme280, NULL);

    return config.read_sensors_period * 1000;
}

void app_set_outside_temperature(int16_t temp) {
    outside_temperature = temp;
}

int16_t app_get_outside_temperature() {

    for(uint8_t i = 0; i < bind_outside_sensor.used; i++) {
        if (bind_outside_sensor.cluster_id[i] == ZCL_CLUSTER_MS_TEMPERATURE_MEASUREMENT) {
            return outside_temperature;
        }
    }
    return 0x8000;
}

void app_set_outside_humidity(uint16_t hum) {
    outside_humidity = hum;
}

uint16_t app_get_outside_humidity() {
    for(uint8_t i = 0; i < bind_outside_sensor.used; i++) {
        if (bind_outside_sensor.cluster_id[i] == ZCL_CLUSTER_MS_RELATIVE_HUMIDITY) {
            return outside_humidity;
        }
    }
    return 0xffff;
}

void app_set_outside_battery(uint8_t percent) {
    outside_battery_percent = percent;
}

uint8_t app_get_outside_battery() {
    for(uint8_t i = 0; i < bind_outside_sensor.used; i++) {
        if (bind_outside_sensor.cluster_id[i] == ZCL_CLUSTER_GEN_POWER_CFG) {
            return outside_battery_percent;
        }
    }
    return 0xff;
}
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

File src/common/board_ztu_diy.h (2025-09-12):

#ifndef SRC_COMMON_BOARD_ZTU_DIY_H_
#define SRC_COMMON_BOARD_ZTU_DIY_H_

#if 1 //VOLTAGE_DETECT_ENABLE
#define VOLTAGE_DETECT_ADC_PIN      GPIO_PC5
#endif


/************************* Configure KEY GPIO ***************************************/
#define MAX_BUTTON_NUM  1

#define BUTTON1                 GPIO_PA0
#define PA0_FUNC                AS_GPIO
#define PA0_OUTPUT_ENABLE       OFF
#define PA0_INPUT_ENABLE        ON
#define PULL_WAKEUP_SRC_PA0     PM_PIN_PULLUP_10K //PM_PIN_PULLUP_1M //

//#define PM_WAKEUP_LEVEL         PM_WAKEUP_LEVEL_LOW

enum {
    VK_SW1 = 0x01,
};

#define KB_MAP_NORMAL   {\
        {VK_SW1,}}

#define KB_MAP_NUM      KB_MAP_NORMAL
#define KB_MAP_FN       KB_MAP_NORMAL

#define KB_DRIVE_PINS  {NULL }
#define KB_SCAN_PINS   {BUTTON1}

/*********************** Configure Sound GPIO **************************************/

#define SOUND_PIN               GPIO_PB5    // PWM5

#define PWM_SOUND_CHANNEL       PWM5_ID
#define PWM_SOUND_CHANNEL_SET() do{ \
                                    gpio_set_func(SOUND_PIN, AS_PWM5); \
                                }while(0)

//#define PB5_FUNC                AS_GPIO
//#define PB5_OUTPUT_ENABLE       ON
//#define PB5_INPUT_ENABLE        OFF

/************************ Configure SPI and other for EPD ***************************/

/* Reset pin */
#define EPD_RST                 GPIO_PD4
#define PD4_FUNC                AS_GPIO
#define PD4_OUTPUT_ENABLE       ON
#define PD4_INPUT_ENABLE        OFF

/* Busy pin */
#define EPD_BUSY                GPIO_PB4
#define PB4_FUNC                AS_GPIO
#define PB4_INPUT_ENABLE        ON
#define PB4_OUTPUT_ENABLE       OFF
#define PULL_WAKEUP_SRC_PB4     PM_PIN_PULLDOWN_100K

/* DC pin */
#define EPD_DC                  GPIO_PA1
#define PA1_FUNC                AS_GPIO
#define PA1_OUTPUT_ENABLE       ON
#define PA1_INPUT_ENABLE        OFF

/* CS pin */
#define EPD_CS                  GPIO_PD2
#define PD2_FUNC                AS_GPIO
#define PD2_OUTPUT_ENABLE       ON
#define PD2_INPUT_ENABLE        OFF

/* SPI Clock */
#define EPD_SPI_CLOCK          2400000//2400K

/*
 *  Define pin for SPI interface
 *          SDO  SDI  SCK  CN
 *          A2   A3   A4   D6
 *          B7   B6   D7   D2
 *
 *          B7 - SDA on epaper
 */
#define EPD_SPI_PIN_GROUP      SPI_GPIO_GROUP_B6B7D2D7
#define EPD_SPI_PIN_CS         EPD_CS

/********************* Configure fake LED for bootloader ***************************/

#if (__PROJECT_TL_BOOT_LOADER__)
#define LED_STATUS              GPIO_PD7
#define PD7_FUNC                AS_GPIO
#define PD7_OUTPUT_ENABLE       ON
#define PD7_INPUT_ENABLE        OFF

#define LED_POWER               GPIO_PC0
#define PC0_FUNC                AS_GPIO
#define PC0_OUTPUT_ENABLE       ON
#define PC0_INPUT_ENABLE        OFF

#define LED_PERMIT              LED_STATUS
#else

/************************ Configure SPI for LED ***************************/

/* CS pin */
#define LED_CS                  GPIO_PC1
#define PC1_FUNC                AS_GPIO
#define PC1_OUTPUT_ENABLE       ON
#define PC1_INPUT_ENABLE        OFF

/* SPI Clock */
#define LED_SPI_CLOCK           2400000//2400K

/*
 *  Define pin for SPI interface
 *          SDO  SDI  SCK  CN
 *          A2   A3   A4   D6
 *          B7   B6   D7   D2
 *
 *          B7 - SDA on epaper
 */
#define LED_SDO                 GPIO_PB7
#define LED_SPI_PIN_GROUP       SPI_GPIO_GROUP_B6B7D2D7
#define LED_SPI_PIN_CS          LED_CS

#define LED_COLOR_RGB           1
#define LED_COLOR_GRB           2

#define LED_BIT_SEQUENCE        LED_COLOR_GRB //LED_COLOR_RGB //

#endif

/************************ Configure I2C for sensors ***************************
 *
 * PC2 - SDA
 * PC3 - SCL
 *
 */

#define I2C_PIN_GROUP       I2C_GPIO_GROUP_C2C3
#define I2C_CLOCK           200000//200K




#if UART_PRINTF_MODE
#define DEBUG_INFO_TX_PIN       UART_TX_PB1    //printf
#define DEBUG_BAUDRATE          115200

#endif /* UART_PRINTF_MODE */

#endif /* SRC_COMMON_BOARD_ZTU_DIY_H_ */

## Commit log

2025-04-17 add temperature
2025-05-04 fix type for temperature, humidity, pressure
    [app_bme280.c]
2025-05-04 fix epaper's fonts and sleep mode
    [epaper.c]
2025-05-15 add addressable LED
2025-05-24 continue
    added force reporing when push key 1 time
    added joine to net only after long pessed key
    added force calibration and factory reset for scd4x sensor
    [app_button.c, app_config.h, app_led.c]
2025-06-21 add type led RGB and GRB
2025-06-22 fixed external data when factory reset
    [app_button.c, app_sensors.c]
2025-07-05 tags for sensors have been added to the log
2025-07-05 commented printf
2025-07-05 new speed SPI for EPD
2025-09-02 added button press check
2025-09-12 new sound with PWM
2026-01-29 fixed an issue with temperature display on the screen
2026-04-11 the button polling procedure has been changed
